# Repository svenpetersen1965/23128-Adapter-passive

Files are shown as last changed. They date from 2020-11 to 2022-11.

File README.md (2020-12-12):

# 23128-Adapter-passive
This is an EPROM adapter for Commodore C16 (C254). It also works as a kernal adapter for the C64 (4x BASIC+Kernal). The better option for the C64 can be found <a href="https://github.com/svenpetersen1965/C64-Kernal-Adaptor-Switch-short-board-">here</a>

It allows up to 4 Kernals for the C16, which can be selected by jumpers.

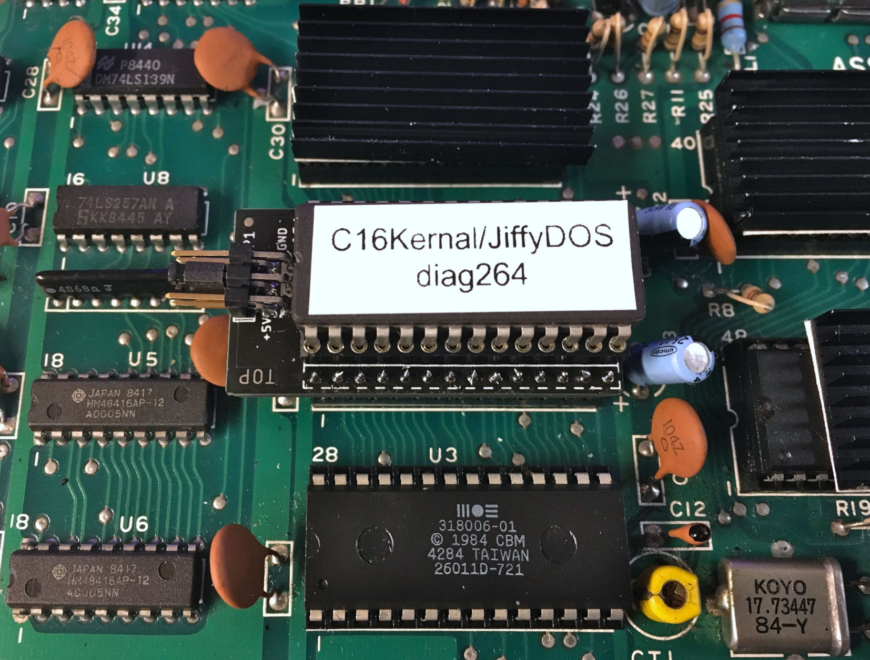
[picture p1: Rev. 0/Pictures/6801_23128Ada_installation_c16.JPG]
23128 EPROM Adapter


BOM value (12.12.2020): 3.81€

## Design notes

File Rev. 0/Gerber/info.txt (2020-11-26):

      
       Board: 23128_adapter_passive
       Rev.:  0
  
       Files:
       ======
  
       All Gerber files are generated in extended gerber format (RS274X)
       *.TOP        : Film top copper
       *.BOT        :  -"- bottom copper
       *.STC        :  -"- top soldermask 
       *.STS        :  -"- bottom soldermask
       *.PLC        :  -"- silk screen top
       *.PLS        :  -"- silk screen bottom
       *.CRC        :  -"- cream top
       *.DK         : Drills plated Through (Excellon)
       *.NDK        : Drills not plated Through (Excellon)
       *.OUT        : Board outline

       Board Size:
       ===========
       Length     :   45.0 mm
       Width      :   22.0 mm
       Thickness  :   1.6 mm
       Material   :   FR 4
       Copper     :   35 um
       Surface    :   HASL
       
       Remarks:
       ========
       minimum drill: 0.35mm
       minimum width: 8 mil
       minimum distance: 6 mil

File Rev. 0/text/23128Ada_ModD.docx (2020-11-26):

Commodore: 23128 Adapter Passive Rev. 0

Module Description

# Introduction

This board serves for adapting an EPROM type 27C128, 27C256 or 27C512 to a 23128 ROM socket. This is useful for e.g. for the Commodore C16 Kernal or the Kernal/Basic ROM of the C64.

A 27C256 or 27C512 fits 32k or 64k, which the size of the 23128 ROM is 16k. The selected 16k bank can be configured with a jumper JP1. A set jumper is LOW, an open jumper is HIGH.

Signal | Pin | Pin | Signal
A14 | 1 | 2 | GND
A15 | 3 | 4 | GND
+5V | 5 | 6 | n.c.

Table 1: Jumper (JP1) for Bank Selection

n.c. is not connected. The purpose of the +5V pin is providing supply voltage to a micro controller or logic circuit for switching between the Kernals.

JP1 can be configured with solder bridges, a pin header and jumpers are not required for a fix configuration.

There are jumpers (JP2, JP4 and JP4) for the chip select of the 23128 on the bottom side of the board. These are configured correctly already, see the schematics for more information. Only one of those should be closed. They are for future use.

# Bank Selection

The desired KERNAL (or other binary content) is selected at JP1. For the pinout refer to Table 1. The jumper is installed (vertically) in a way, that it connects the address line with the GND potential.

A15 | A14 | 16k Block | Addr. Offset
set | set | #0 | 0x0000
set | open | #1 | 0x4000
open | set | #2 | 0x8000
open | open | #3 | 0xC000

Table 2: Selection of EPROM memory blocks

A set jumper corresponds to a LOW level (binary 0), an open jumper to a HIGH level. The EPROM Offset Address and the C16/C64 address must not be confused.

# Dimensions

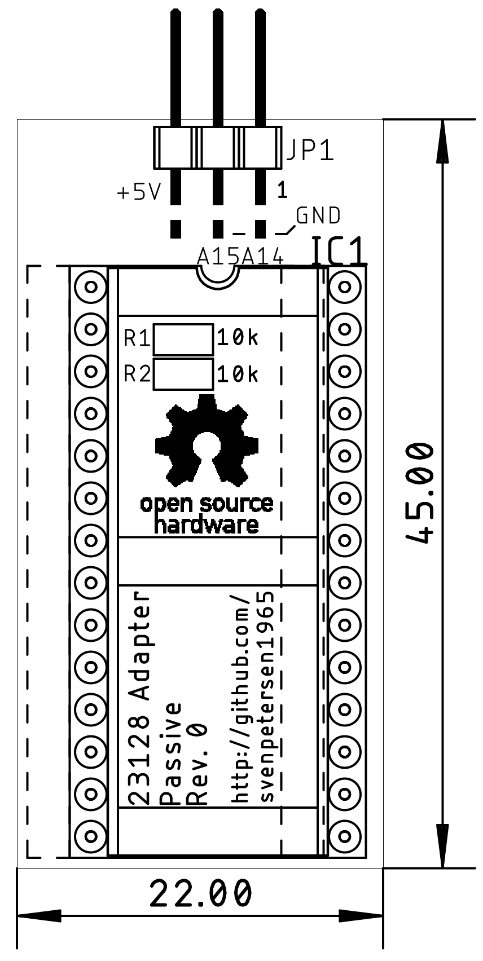
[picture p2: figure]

Figure 1: Dimensions

# Sources for BASIC and KERNAL for the C16

The content of the BASIC ROM (The BASIC ROM fits this adapter, too) and the KERNAL ROM can be found here:

http://www.zimmers.net/anonftp/pub/cbm/firmware/computers/c64/index.html

(http://www.zimmers.net/anonftp/pub/cbm/firmware/computers/plus4/index.html)There are different Kernals for PAL and for NTSC machines. Be aware that you need the one, that fits your C16.

The popular JiffyDOS is still a commercial product and can be acquired for little money from

http://www.go4retro.com/ or https://restore-store.de/

# Compatibility of EPROMs

It is recommended to use 27C512 EPROMs only. The smaller EPROM Types 27C256 and 27C128 might conflict with accessing the BASIC 8k slot. The unused address signals will be tied LOW while this access. This means, VPP will be approximately 0V and /PGM will be LOW. This is a not recommended setting.

27C128
| 27C256
| | 27C512
| | | SOCKET
VPP | VPP | A15 | 1 | A15 | VCC | 28 | VCC | VCC | VCC
A12 | A12 | A12 | 2 | A12 | A14 | 27 | A14 | A14 | /PGM
A7 | A7 | A7 | 3 | A7 | A13 | 26 | A13 | A13 | A13
A6 | A6 | A6 | 4 | A6 | A8 | 25 | A8 | A8 | A8
A5 | A5 | A5 | 5 | A5 | A9 | 24 | A9 | A9 | A9
A4 | A4 | A4 | 6 | A4 | A11 | 23 | A11 | A11 | A11
A3 | A3 | A3 | 7 | A3 | /OE | 22 | /G/Vpp | /G | /G
A2 | A2 | A2 | 8 | A2 | A10 | 21 | A10 | A10 | A10
A1 | A1 | A1 | 9 | A1 | GND | 20 | /E | /E | /E
A0 | A0 | A0 | 10 | A0 | D7 | 19 | D7 | D7 | D7
D0 | D0 | D0 | 11 | D0 | D6 | 18 | D6 | D6 | D6
D1 | D1 | D1 | 12 | D1 | D5 | 17 | D5 | D5 | D5
D2 | D2 | D2 | 13 | D2 | D4 | 16 | D4 | D4 | D4
GND | GND | GND | 14 | GND | D3 | 15 | D3 | D3 | D3

Table 3: EPROM pin compatibility

EPROM | Size | A15 | A14
27C512 | 64kx8 | yes | yes
27C256 | 32kx8 | HIGH | yes
27C128 | 16kx8 | HIGH | HIGH

Table 4: Settings per EPROM type

In case VPP is located at a dedicated pin (pin 1), A15 has no effect anymore. A HIGH level is recommended (switch is off). The /PGM Pin should be set HIGH. The n.c. (not connected) pin should be HIGH (with pull-up) or open.

# Using parallel EEPROMs

There are parallel EPROMs, which fit into the EPROM sockets. They do not require erasing with a UV eraser, like EPROMs, but the price is higher.

Since they can be written, which is controlled by the signal, but the Super Expander II cartridge is lacking of this functionality, this signal has to be HIGH (inactive). The 28C256 has the A14 signal connected to Pin 1, which is A15 of the EEPROM socket. This is no problem, but it has to be kept in mind, that the jumper for A15 has effect on the bank select A14 of the EPROM.

28C256
| SOCKET
A14 | 1 | A15 | VCC | 28 | VCC
A12 | 2 | A12 | A14 | 27 | /WE
A7 | 3 | A7 | A13 | 26 | A13
A6 | 4 | A6 | A8 | 25 | A8
A5 | 5 | A5 | A9 | 24 | A9
A4 | 6 | A4 | A11 | 23 | A11
A3 | 7 | A3 | /OE | 22 | /G/Vpp
A2 | 8 | A2 | A10 | 21 | A10
A1 | 9 | A1 | GND | 20 | /E
A0 | 10 | A0 | D7 | 19 | D7
D0 | 11 | D0 | D6 | 18 | D6
D1 | 12 | D1 | D5 | 17 | D5
D2 | 13 | D2 | D4 | 16 | D4
GND | 14 | GND | D3 | 15 | D3

Table 5: EEPROM pin compatibility

EEPROM | Size | A15 | A14
28C256 | 32kx8 | =A14 | OPEN

Table 6: Settings per EEPROM type

# Installation

The 23128 Adapter can be installed on a C64 short board (for BASIC and Kernal) or a C16 (C264 family) in the Kernal socket (U4) or the BASIC socket (U3). The notch that marks the direction of the socket and on the EPROM have to point in the same direction.


Figure 2: The 23128 Adapter installed in the U4 Kernals socket on a C16 board

# Revision History

## Rev. 0

- Fully functional prototype

23128Ada_ModD.docx 26.11.2020 13:36 Drafted by Sven Petersen Page 2 of 2 Doc.-No.: 168-6-01-00

23128Ada_ModD.docx 26.11.2020 13:36 Drafted by Sven Petersen Page 1 of 1 Doc.-No.: 000-6-00-00

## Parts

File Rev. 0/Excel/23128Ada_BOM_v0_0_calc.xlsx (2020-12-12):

Commodore: 23128 Adapter, passive Rev. 0
Calculation Rev. 0.0
Pos. | Qty | Value | €/ea | € | Comment
1 | 1 | 168-2-01-00 | 1.00 € | 1.00 € | 2 layer, Cu 35µ, HASL, 45.0 x 22.0, 1.6mm FR4
2 | 2 | 10k | 0.08 € | 0.16 € | SMD resistor, 10% or better
3 | 1 | two Pinstrip, precision round pins, cut to 14 pins length | 1.99 € | 1.99 € | Precision Round pins mandatory! E.g. Reichelt BKL 10120540 or
4 |  |  |  | 0.00 € | 10PCS Single Row 40Pin 2.54mm Round Male Pin Header machined (https://www.ebay.de/itm/10PCS-Single-Row-40Pin-2-54mm-Round-Male-Pin-Header-machined/281821698031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)
5 | 1 | 2x03pin/90° | 0.20 € | 0.20 € | 90° pin header, 2.54mm pitch. E.g. Reichelt MPE 088-2-006, not required for fix configuration
6 | 2 | Jumper | 0.02 € | 0.04 € | Jumpers for address selection (in case it is intended to jumper the kenal selection)
7 | 1 | DIP28 socket | 0.42 € | 0.42 € | Precision round pin is recommended
8 |  | Total |  | 3.81 €

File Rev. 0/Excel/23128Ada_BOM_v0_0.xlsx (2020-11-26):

Commodore: 23128 Adapter, passive Rev. 0
Bill of Material Rev. 0.0
Pos. | Qty | Value | Footprint | Ref.-No. | Comment
1 | 1 | 168-2-01-00 | 2 Layer | PCB Rev. 0 | 2 layer, Cu 35µ, HASL, 45.0 x 22.0, 1.6mm FR4
2 | 2 | 10k | 0805 | R1, R2 | SMD resistor, 10% or better
3 | 1 | two Pinstrip, precision round pins, cut to 14 pins length | DIL28_SOCKET | (IC2) | Precision Round pins mandatory! E.g. Reichelt BKL 10120540 or
4 |  |  |  |  | 10PCS Single Row 40Pin 2.54mm Round Male Pin Header machined (https://www.ebay.de/itm/10PCS-Single-Row-40Pin-2-54mm-Round-Male-Pin-Header-machined/281821698031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)
5 | 1 | 2x03pin/90° | COMBI-3X2W | JP1 | 90° pin header, 2.54mm pitch. E.g. Reichelt MPE 088-2-006, not required for fix configuration
6 | 2 | Jumper | 2.54mm | (JP1) | Jumpers for address selection (in case it is intended to jumper the kenal selection)
7 | 1 | DIP28 socket | DIL28-6 | (IC1) | Precision round pin is recommended

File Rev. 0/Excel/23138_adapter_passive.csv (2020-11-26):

Qty | Value | Device | Package | Parts | Description
1 |  | CLOSED | CP_CL | JP2 | Closed Cutpad
2 |  | OPEN | CP_OP | JP3, JP4 | open Cutpad
2 | 10k | R-0805 | 0805 | R1, R2
1 | 23128SOCKET | 23128SOCKET | DIL28_SOCKET | IC2
1 | COMBI-3X2P-90° | COMBI-3X2P-90° | COMBI-3X2W | JP1
1 | M27C512-DIP28 | M27C512-DIP28 | DIL28-6 | IC1
1 | OPEN_SOURCE_HW | OPEN_SOURCE_HW | OPENHW | U$21

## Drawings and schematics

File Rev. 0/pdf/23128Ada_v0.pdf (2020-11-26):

# Project Documentation

## Commodore: 23128 Adapter Passive

## Project number: 168

## Revision: 0

## Date: 29.10.2020

23128Ada_ModD.docx | | 26.11.2020 13:36
Drafted by Sven Petersen | Page 1 of 5 | Doc.-No.: 168-6-01-00

### Commodore: 23128 Adapter Passive Rev. 0

### Module Description

Table of Contents

## Introduction

This board serves for adapting an EPROM type 27C128, 27C256 or 27C512 to a 23128 ROM socket. This is useful for e.g. for the Commodore C16 Kernal or the Kernal/Basic ROM of the C64.

A 27C256 or 27C512 fits 32k or 64k, which the size of the 23128 ROM is 16k. The selected 16k bank can be configured with a jumper JP1. A set jumper is LOW, an open jumper is HIGH.

Signal Pin | Pin Signal
A14 | 1 | 2 | GND
A15 | 3 | 4 | GND
+5V | 5 | 6 | n.c.
Table 1: Jumper (JP1) for Bank Selection

n.c. is not connected. The purpose of the +5V pin is providing supply voltage to a micro controller or logic circuit for switching between the Kernals.

JP1 can be configured with solder bridges, a pin header and jumpers are not required for a fix configuration.

There are jumpers (JP2, JP4 and JP4) for the chip select of the 23128 on the bottom side of the board. These are configured correctly already, see the schematics for more information. Only one of those should be closed. They are for future use.

## Bank Selection

The desired KERNAL (or other binary content) is selected at JP1. For the pinout refer to Table 1. The jumper is installed (vertically) in a way, that it connects the address line with the GND potential.


23128Ada_ModD.docx | | 26.11.2020 13:36
Drafted by Sven Petersen | Page 2 of 5 | Doc.-No.: 168-6-01-00
A15 | A14 | 16k Block Addr. Offset
set | set | #0 | 0x0000
set | open | #1 | 0x4000
open | set | #2 | 0x8000
open | open | #3 | 0xC000
Table 2: Selection of EPROM memory blocks

A set jumper corresponds to a LOW level (binary 0), an open jumper to a HIGH level. The EPROM Offset Address and the C16/C64 address must not be confused.

## Dimensions

Figure 1: Dimensions

## Sources for BASIC and KERNAL for the C16

The content of the BASIC ROM (The BASIC ROM fits this adapter, too) and the KERNAL ROM can be found here:

http://www.zimmers.net/anonftp/pub/cbm/firmware/computers/c64/index.html

There are different Kernals for PAL and for NTSC machines. Be aware that you need the one, that fits your C16.

The popular JiffyDOS is still a commercial product and can be acquired for little money from

http://www.go4retro.com/ or https://restore-store.de/

23128Ada_ModD.docx | | 26.11.2020 13:36
Drafted by Sven Petersen | Page 3 of 5 | Doc.-No.: 168-6-01-00

## Compatibility of EPROMs

It is recommended to use 27C512 EPROMs only. The smaller EPROM Types 27C256 and 27C128 might conflict with accessing the BASIC 8k slot. The unused address signals will be tied LOW while this access. This means, VPP will be approximately 0V and /PGM will be LOW. This is a not recommended setting.

27C128
| 27C256
| 27C512
| SOCKET
VPP | VPP | A15 | 1 | A15 | VCC | 28 | VCC | VCC | VCC
A12 | A12 | A12 | 2 | A12 | A14 | 27 | A14 | A14 | /PGM
A7 | A7 | A7 | 3 | A7 | A13 | 26 | A13 | A13 | A13
A6 | A6 | A6 | 4 | A6 | A8 | 25 | A8 | A8 | A8
A5 | A5 | A5 | 5 | A5 | A9 | 24 | A9 | A9 | A9
A4 | A4 | A4 | 6 | A4 | A11 | 23 | A11 | A11 | A11
A3 | A3 | A3 | 7 | A3 | /OE | 22 | /G/Vpp | /G | /G
A2 | A2 | A2 | 8 | A2 | A10 | 21 | A10 | A10 | A10
A1 | A1 | A1 | 9 | A1 | GND | 20 | /E | /E | /E
A0 | A0 | A0 | 10 | A0 | D7 | 19 | D7 | D7 | D7
D0 | D0 | D0 | 11 | D0 | D6 | 18 | D6 | D6 | D6
D1 | D1 | D1 | 12 | D1 | D5 | 17 | D5 | D5 | D5
D2 | D2 | D2 | 13 | D2 | D4 | 16 | D4 | D4 | D4
GND | GND | GND | 14 | GND | D3 | 15 | D3 | D3 | D3
Table 3: EPROM pin compatibility
EPROM | Size | A15 | A14
27C512 | 64kx8 | yes | yes
27C256 | 32kx8 | HIGH | yes
27C128 | 16kx8 | HIGH | HIGH
Table 4: Settings per EPROM type

In case VPP is located at a dedicated pin (pin 1), A15 has no effect anymore. A HIGH level is recommended (switch is off). The /PGM Pin should be set HIGH. The n.c. (not connected) pin should be HIGH (with pull-up) or open.

23128Ada_ModD.docx | | 26.11.2020 13:36
Drafted by Sven Petersen | Page 4 of 5 | Doc.-No.: 168-6-01-00
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

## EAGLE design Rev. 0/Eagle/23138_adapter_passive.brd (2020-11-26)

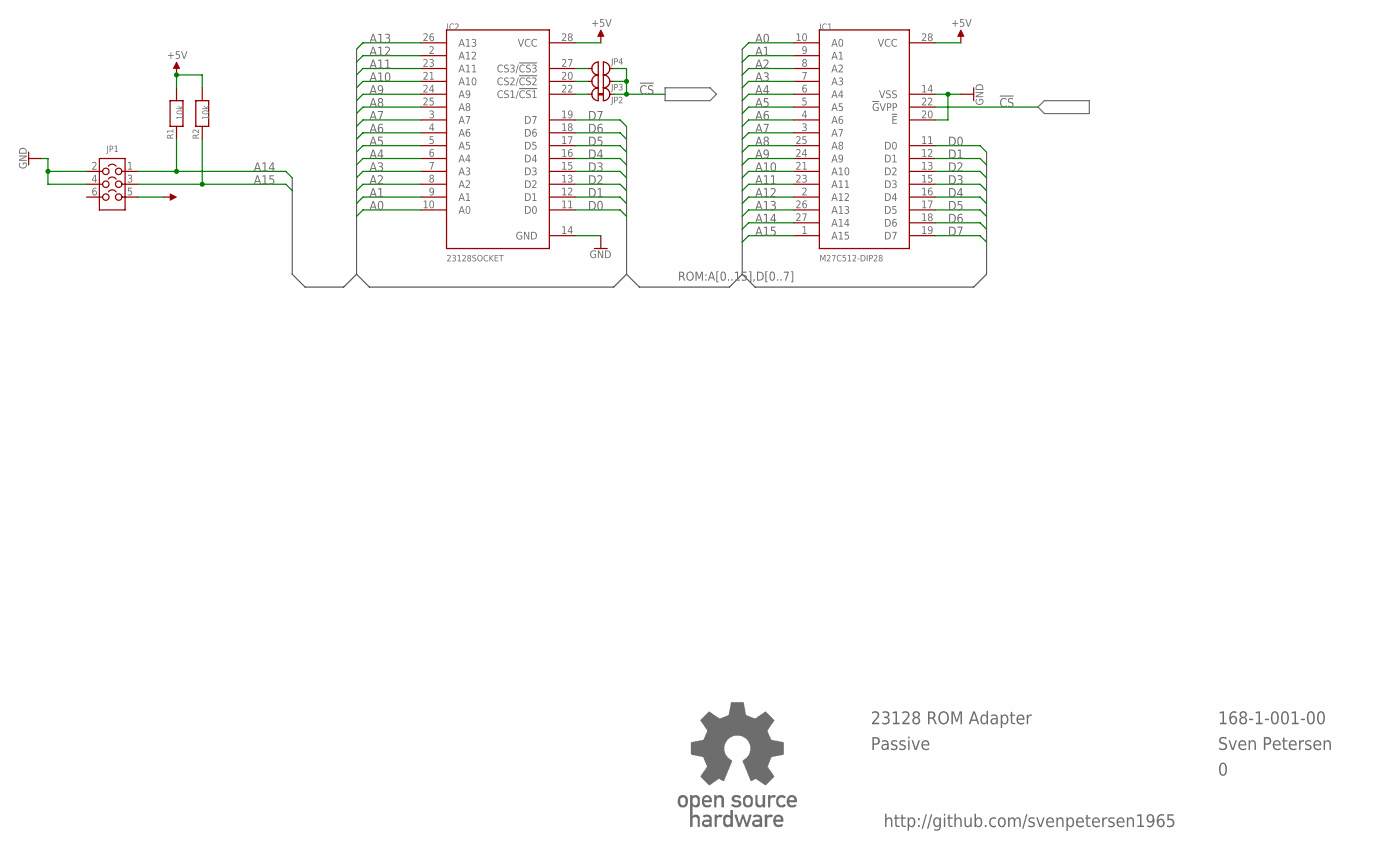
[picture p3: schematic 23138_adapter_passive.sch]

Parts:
IC1: M27C512-DIP28; DIL28-6
IC2: 23128SOCKET; DIL28_SOCKET
JP1: COMBI-3X2P-90°; COMBI-3X2W
JP2: CLOSED; CP_CL
JP3, JP4: OPEN; CP_OP
R1, R2: 10k; 0805
U$21: OPEN_SOURCE_HW; OPENHW

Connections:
!CS: IC1.22 (!G!VPP), JP2.2, JP3.2, JP4.2
+5V: IC1.28 (VCC), IC2.28 (VCC), JP1.5, R1.2, R2.2
A0: IC1.10 (A0), IC2.10 (A0)
A1: IC1.9 (A1), IC2.9 (A1)
A2: IC1.8 (A2), IC2.8 (A2)
A3: IC1.7 (A3), IC2.7 (A3)
A4: IC1.6 (A4), IC2.6 (A4)
A5: IC1.5 (A5), IC2.5 (A5)
A6: IC1.4 (A6), IC2.4 (A6)
A7: IC1.3 (A7), IC2.3 (A7)
A8: IC1.25 (A8), IC2.25 (A8)
A9: IC1.24 (A9), IC2.24 (A9)
A10: IC1.21 (A10), IC2.21 (A10)
A11: IC1.23 (A11), IC2.23 (A11)
A12: IC1.2 (A12), IC2.2 (A12)
A13: IC1.26 (A13), IC2.26 (A13)
A14: IC1.27 (A14), JP1.1, R1.1
A15: IC1.1 (A15), JP1.3, R2.1
D0: IC1.11 (D0), IC2.11 (D0)
D1: IC1.12 (D1), IC2.12 (D1)
D2: IC1.13 (D2), IC2.13 (D2)
D3: IC1.15 (D3), IC2.15 (D3)
D4: IC1.16 (D4), IC2.16 (D4)
D5: IC1.17 (D5), IC2.17 (D5)
D6: IC1.18 (D6), IC2.18 (D6)
D7: IC1.19 (D7), IC2.19 (D7)
GND: IC1.14 (VSS), IC1.20 (!E), IC2.14 (GND), JP1.2, JP1.4
unnamed: IC2.22 (CS1/!CS1), JP2.1
unnamed: IC2.27 (CS3/!CS3), JP4.1
unnamed: IC2.20 (CS2/!CS2), JP3.1

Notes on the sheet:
168-1-001-00
Sven Petersen
23128 ROM Adapter
Passive
http://github.com/svenpetersen1965

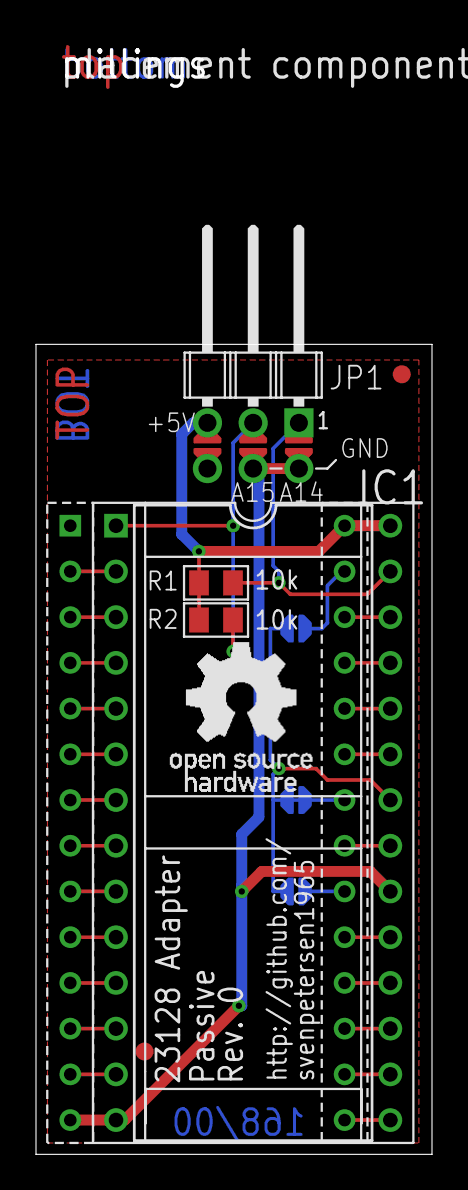
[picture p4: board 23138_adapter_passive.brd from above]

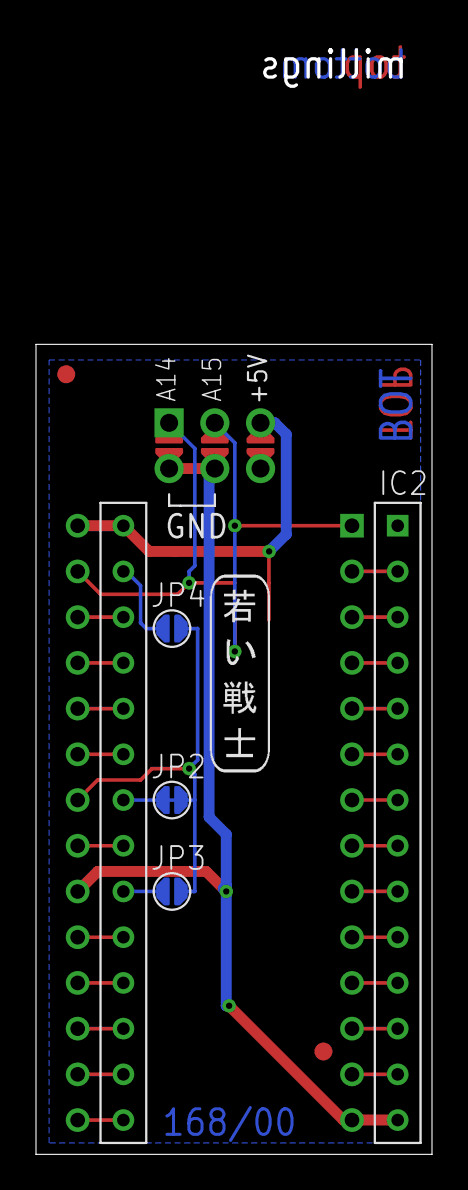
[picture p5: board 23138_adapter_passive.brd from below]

Board: 2 copper layers, 22.0 x 45.0 mm, 15 parts (4 on the bottom side), 30 nets.

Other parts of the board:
U$16: GS28P
U$17, U$18: SMD_REF_R1MM
U$19: 2LAYER
U$20: PCB-TITLE/
U$22: SVEN_TAG

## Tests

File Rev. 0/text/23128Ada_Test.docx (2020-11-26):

Commodore: 23128 Adapter Passive Rev. 0

Test

# Test Setup

The passive 23128 Adapter (Rev. 0) was tested in a Commodore C16 (ASSY 250443 Rev B). An ST M27C512 EPROM with the following binaries was installed:

Offset Address | Memory Bank | Binary
$0000 | 0 | Commodore PAL Kernal (318004-05)
$4000 | 1 | JiffyDOS 6.01 for C16 (PAL)
$8000 | 2 | Diag264 (PAL)
$C000 | 3 | empty

# Test Execution

The C16 was powered down for setting the jumpers, the jumpers were set and the C16 was powered up again.

Jumpers JP1 | Boots to | Testing
A14 and A15 | Normal Kernal | ok
A15 only | JiffyDOS | ok
A14 only | Diag264 | ok

The Kernals were tested, no problems have occurred. All configuration addresses are effective.

# Conclusion

The 23128 Adapter is fully functional.

23128Ada_Test.docx 26.11.2020 13:51 Drafted by Sven Petersen Page 2 of 2 Doc.-No.: 164-6-02-00

23128Ada_Test.docx 26.11.2020 13:51 Drafted by Sven Petersen Page 1 of 1 Doc.-No.: 000-6-00-00

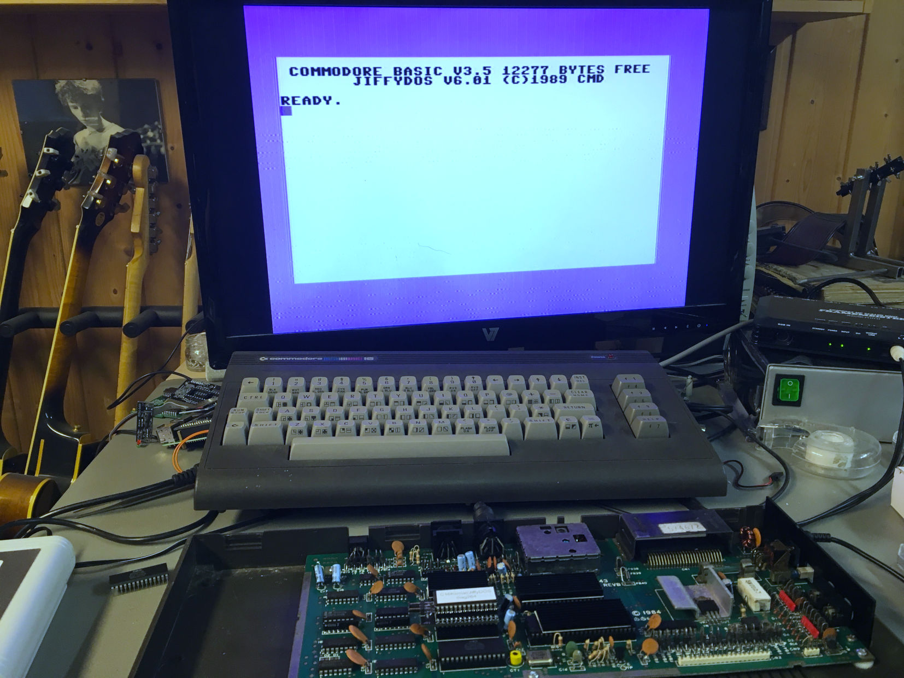
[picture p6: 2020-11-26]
Rev. 0/Pictures/6800_23128Ada_Test.JPG
